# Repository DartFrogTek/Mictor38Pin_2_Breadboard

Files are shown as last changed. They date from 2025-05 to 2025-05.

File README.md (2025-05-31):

# Mictor 38Pin to Breadboard
A Mictor 38 Pin to Breadboard adapter. Allows Mictor connectors for high end Logic Analyzers to interface with breadboard and/or prototype PCBs.

Renders show dual Male Pin Headers on the top in all spaces. Instead you can place a Female Socket or a set of Male Pins. I would place male pins on bottom side in J2/J5/J4 and solder from top. You can either leave J3/J6/J7 empty or you can add male pins or female sockets to the top if desired. J2/J6 are connected. J4/J7 are connected. J5/J3 are connected.

Order from PCBWay with my shared project!
https://www.pcbway.com/project/shareproject/Mictor_38Pin_Logic_Analyzer_Probe_Breakout_98119768.html

In The Wild

### Female Mictor 38 Pin Connector
- TE Connectivity AMP Connectors [5767061-1](https://www.digikey.com/en/products/detail/te-connectivity-amp-connectors/5767061-1/2195045)
- TE Connectivity AMP Connectors [2-5767004-2](https://www.futureelectronics.com/p/interconnect--dual-in-line-package-sockets/2-5767004-2-te-connectivity-7561798)
  
Both work. (5767061-1) and (2-5767004-2) are identical except:
  - (2-5767004-2)'s 5 through-hole ground pins are slightly under flush with the surface of a 1.6mm FR4 board.
  - (5767061-1)'s 5 through-hole ground pins protrude above by 2.00mm of the surface of a 1.6mm FR4 board.

### Renders
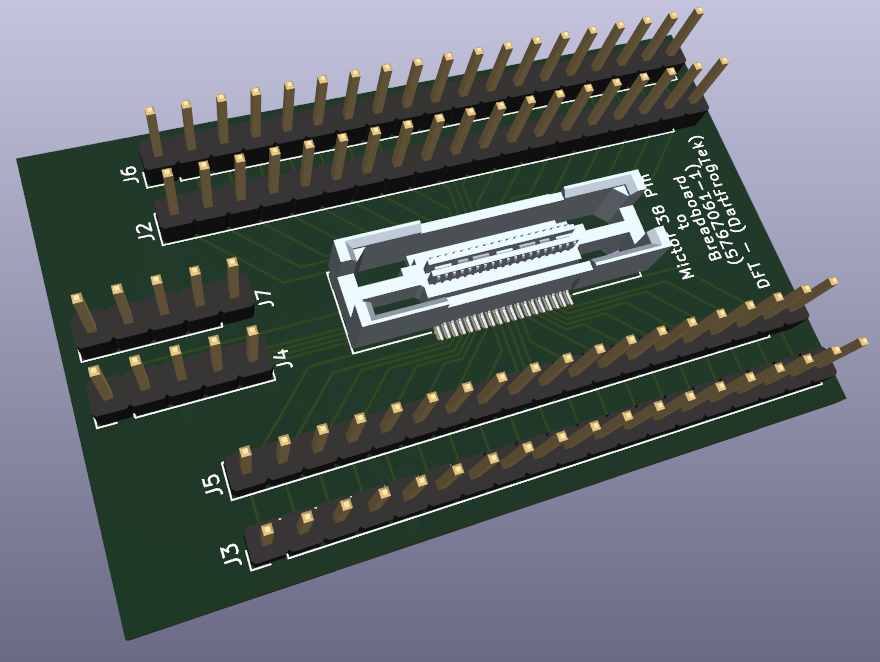
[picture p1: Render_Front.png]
Render Front


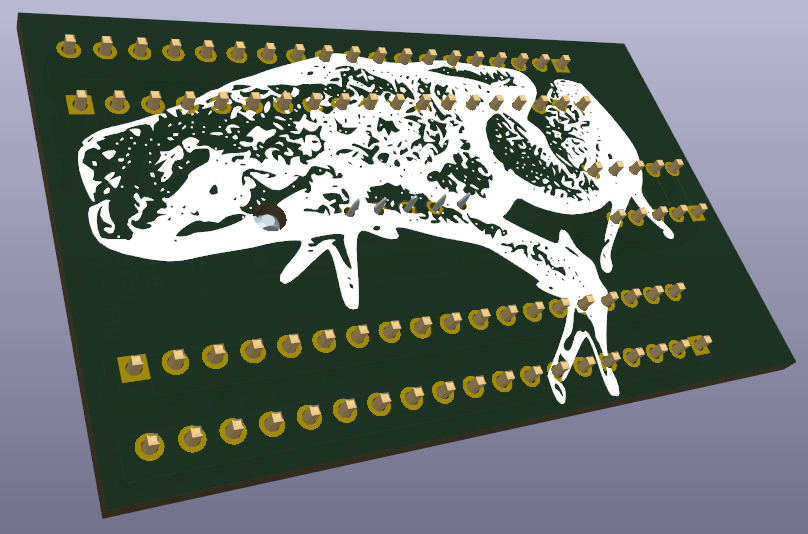
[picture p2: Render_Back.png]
Render Back


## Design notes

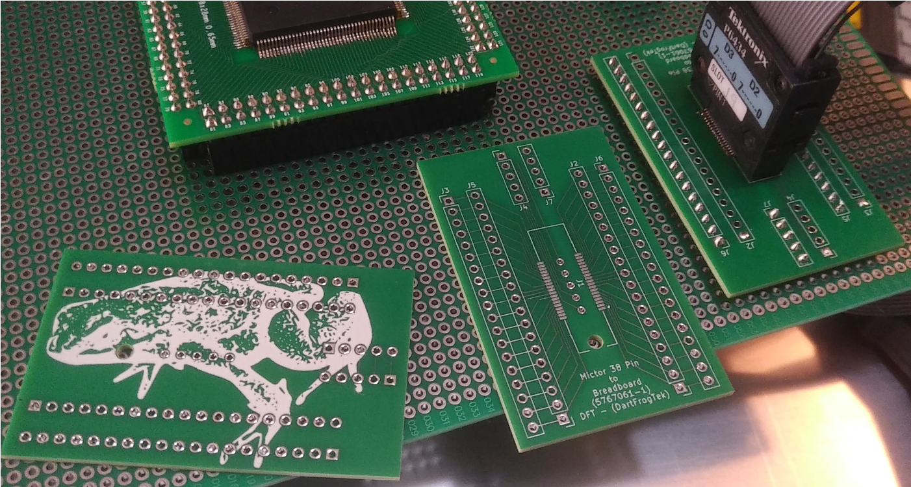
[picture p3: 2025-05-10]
InTheWildSmall.png

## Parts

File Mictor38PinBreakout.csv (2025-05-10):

Reference | Value | Footprint | Datasheet | Qty | DNP | Exclude from BOM | Exclude from Board
J1 | 5767061-1 | Mictor38:TE_5767061-1 |  | 1
J2,J3 | Conn_01x19_Pin | Connector_PinHeader_2.54mm:PinHeader_1x19_P2.54mm_Vertical | ~ | 2
J4 | Conn_01x05_Pin | Connector_PinHeader_2.54mm:PinHeader_1x05_P2.54mm_Vertical | ~ | 1
J5,J6 | Conn_01x19_Socket | Connector_PinHeader_2.54mm:PinHeader_1x19_P2.54mm_Vertical | ~ | 2
J7 | Conn_01x05_Socket | Connector_PinHeader_2.54mm:PinHeader_1x05_P2.54mm_Vertical | ~ | 1

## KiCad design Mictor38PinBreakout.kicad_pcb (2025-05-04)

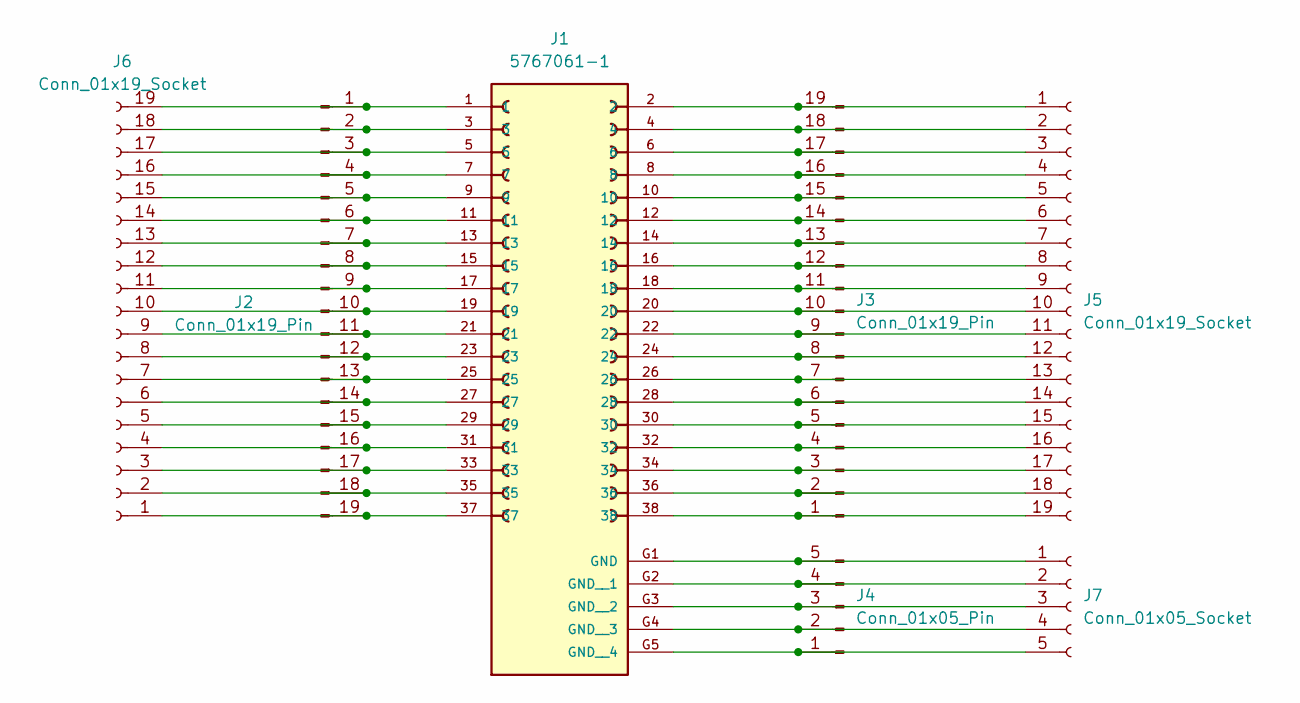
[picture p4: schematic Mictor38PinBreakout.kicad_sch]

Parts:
J1: 5767061-1; TE_5767061-1; PARTREV B1
J2, J3: Conn_01x19_Pin; PinHeader_1x19_P2.54mm_Vertical
J4: Conn_01x05_Pin; PinHeader_1x05_P2.54mm_Vertical
J5, J6: Conn_01x19_Socket; PinHeader_1x19_P2.54mm_Vertical
J7: Conn_01x05_Socket; PinHeader_1x05_P2.54mm_Vertical

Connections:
unnamed: J1.G1 (GND), J4.5, J7.1
unnamed: J1.G2 (GND__1), J4.4, J7.2
unnamed: J1.G3 (GND__2), J4.3, J7.3
unnamed: J1.G4 (GND__3), J4.2, J7.4
unnamed: J1.G5 (GND__4), J4.1, J7.5
unnamed: J1.1, J2.1, J6.19
unnamed: J1.3, J2.2, J6.18
unnamed: J1.5, J2.3, J6.17
unnamed: J1.7, J2.4, J6.16
unnamed: J1.9, J2.5, J6.15
unnamed: J1.11, J2.6, J6.14
unnamed: J1.13, J2.7, J6.13
unnamed: J1.15, J2.8, J6.12
unnamed: J1.17, J2.9, J6.11
unnamed: J1.19, J2.10, J6.10
unnamed: J1.21, J2.11, J6.9
unnamed: J1.23, J2.12, J6.8
unnamed: J1.25, J2.13, J6.7
unnamed: J1.27, J2.14, J6.6
unnamed: J1.29, J2.15, J6.5
unnamed: J1.31, J2.16, J6.4
unnamed: J1.33, J2.17, J6.3
unnamed: J1.35, J2.18, J6.2
unnamed: J1.37, J2.19, J6.1
unnamed: J1.38, J3.1, J5.19
unnamed: J1.36, J3.2, J5.18
unnamed: J1.34, J3.3, J5.17
unnamed: J1.32, J3.4, J5.16
unnamed: J1.30, J3.5, J5.15
unnamed: J1.28, J3.6, J5.14
unnamed: J1.26, J3.7, J5.13
unnamed: J1.24, J3.8, J5.12
unnamed: J1.22, J3.9, J5.11
unnamed: J1.20, J3.10, J5.10
unnamed: J1.18, J3.11, J5.9
unnamed: J1.16, J3.12, J5.8
unnamed: J1.14, J3.13, J5.7
unnamed: J1.12, J3.14, J5.6
unnamed: J1.10, J3.15, J5.5
unnamed: J1.8, J3.16, J5.4
unnamed: J1.6, J3.17, J5.3
unnamed: J1.4, J3.18, J5.2
unnamed: J1.2, J3.19, J5.1

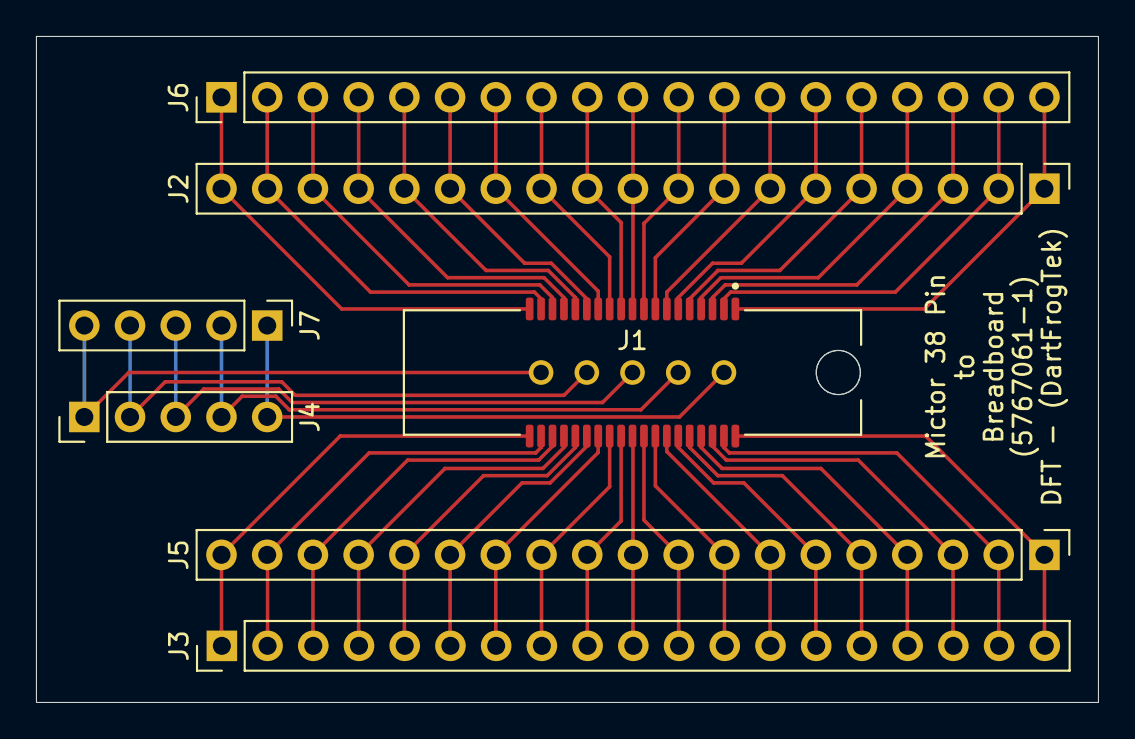
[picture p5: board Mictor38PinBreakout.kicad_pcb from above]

Board: 2 copper layers, 59.0 x 37.0 mm, 7 parts (0 on the bottom side), 43 nets.
